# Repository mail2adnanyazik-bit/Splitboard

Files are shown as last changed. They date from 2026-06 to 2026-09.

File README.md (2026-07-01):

# Splitboard - a custom, built from scratch wireless corne split keyboard. Built for Stardance, to qualify for Outpost.

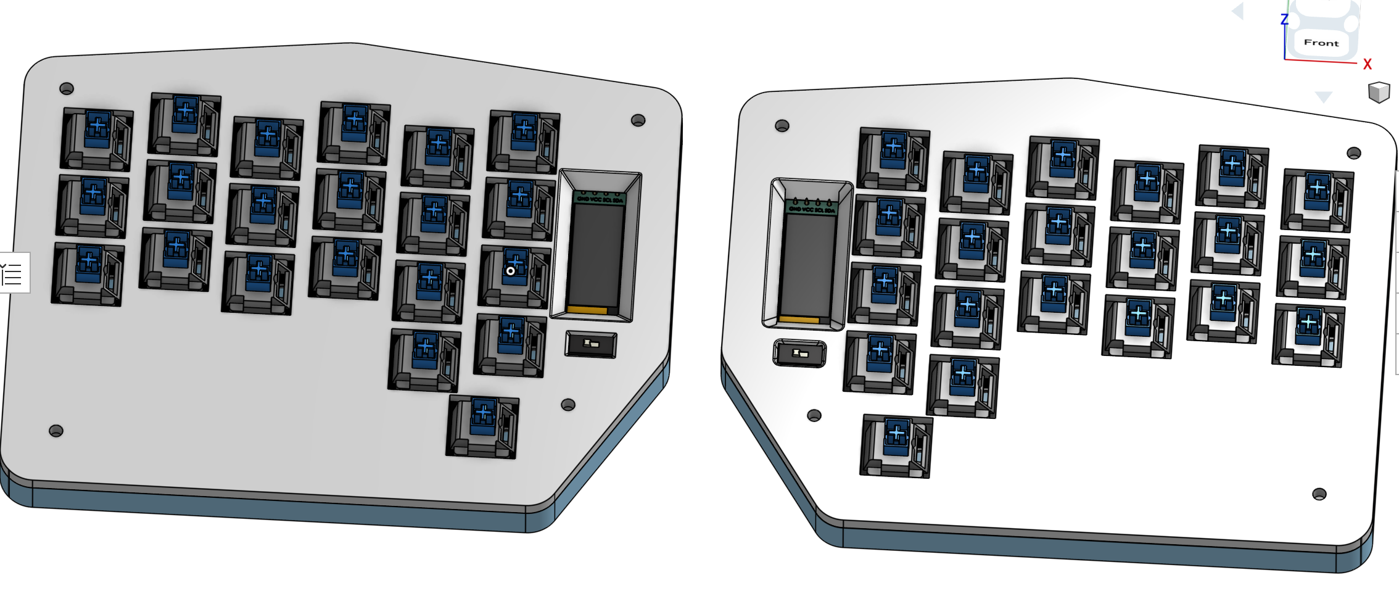
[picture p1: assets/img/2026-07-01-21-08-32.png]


Splitboard is a wireless split keyboard built by ME - Panda (also known as Adnan)

You see, my dad has had a dygma raise split keyboard since like 4 years, and i thought it looked REALLY cool, and wanted to get one -
till i saw the price - the thing was whopping **_200 DOLLARS_** ! So i thought to myself - why not build one myself ?

By the time this event rolled around, i was already getting tired of my very *anti-*ergonomic apple magic keyboard, and thought
that this project would be perfect, expecially cause of the experience with keyboards i got from the Hackpad mission.

That is how the **Splitboard** was born.

## Components :

Since this keyboard was made completely from scratch, i first will tell you whats its made of :

The Split Keyboard has 2 halves, with each having :

- 21 Keys (3x6 matrix with 3 thumb keys) - in the classic Corne layout
- One OLED (blue, since thats myt fav color)
- A supermini nrf52840 microcontroller - this is a cheap nice ! nano v2 clone, a wireless chip made excpecially with keyboards in mind
- A 110 mAh Battery (should last weeks with my setup)

So this is the Schematic with all mentioned components :

## Schematic :

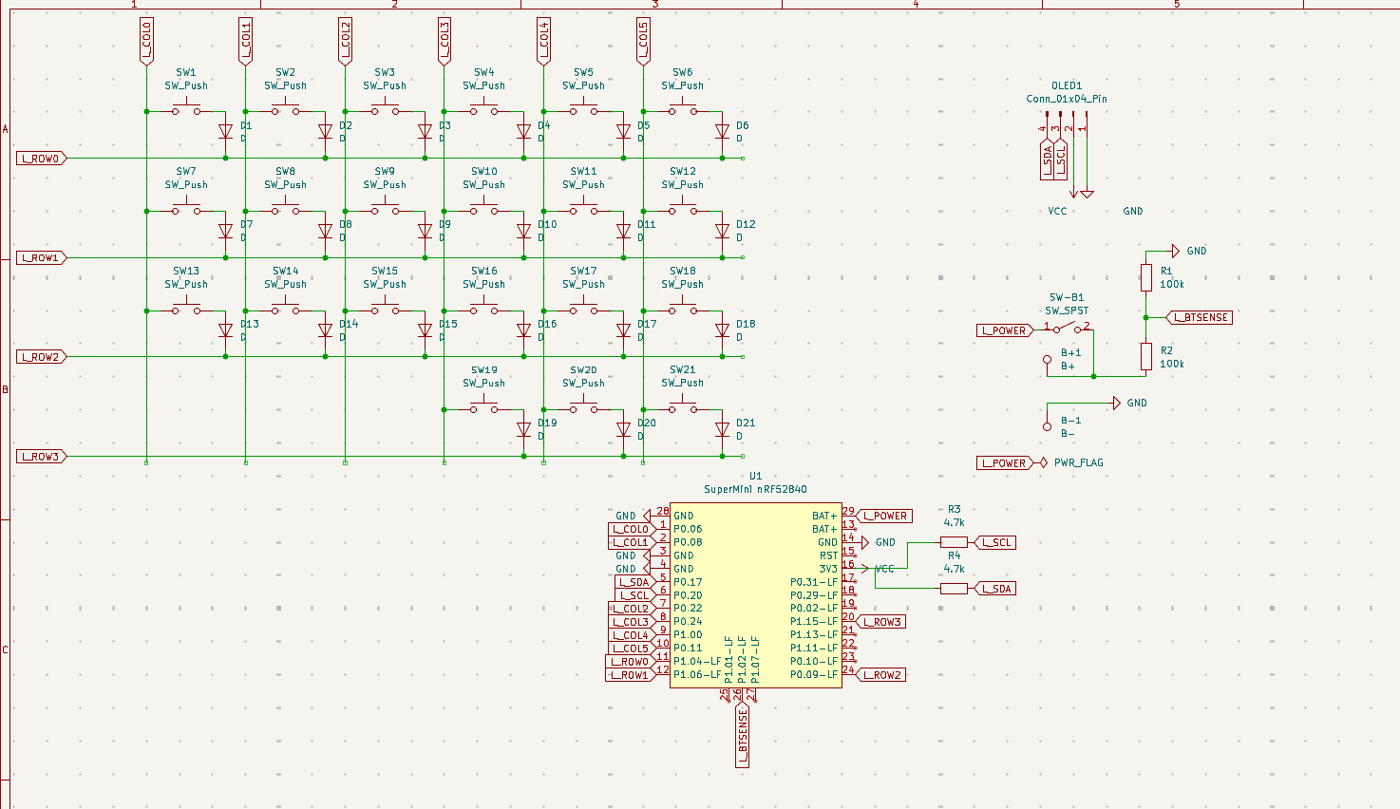
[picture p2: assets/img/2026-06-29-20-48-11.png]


As you can see, i dont like wires :D

## PCB :

left side :

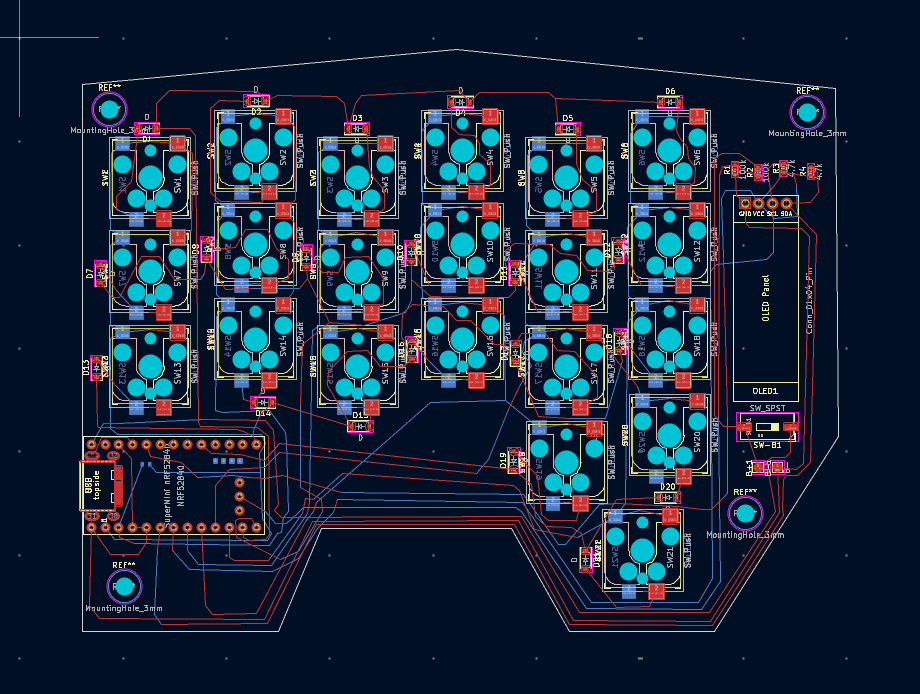
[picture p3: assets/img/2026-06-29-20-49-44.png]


right side :

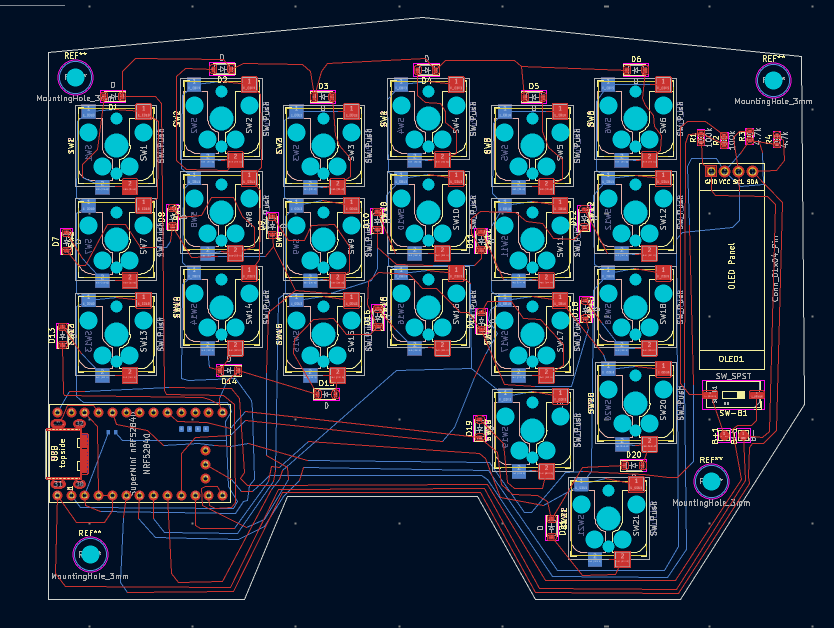
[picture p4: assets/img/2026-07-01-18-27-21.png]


Although the initial plan was to make a _reversible_ PCB that i would just turn 180 degrees, i decided to make my keyboard not symmetric - which means i cant just turn it around, instead i have to make two seperate PCB's

## Case :

You can view it interactively on OnShape in your Browser ! : https://cad.onshape.com/documents/4401902cdc607732e38adc1c/w/b44e538c7538a5811b6e646c/e/3efcd232ff04d945eef59e16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

For the case, i decided to use just two parts :

- ### A Case Bottom :

  This just holds the PCB and components for my keyboard

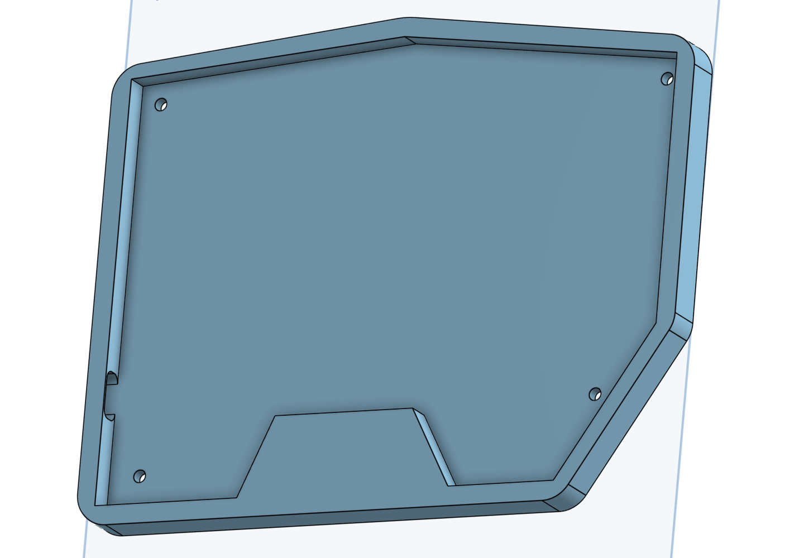
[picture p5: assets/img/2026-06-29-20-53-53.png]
  

- ### A Top Plate :
  This will be screwed on to the base, and has holes for the components that need to look out to poke out
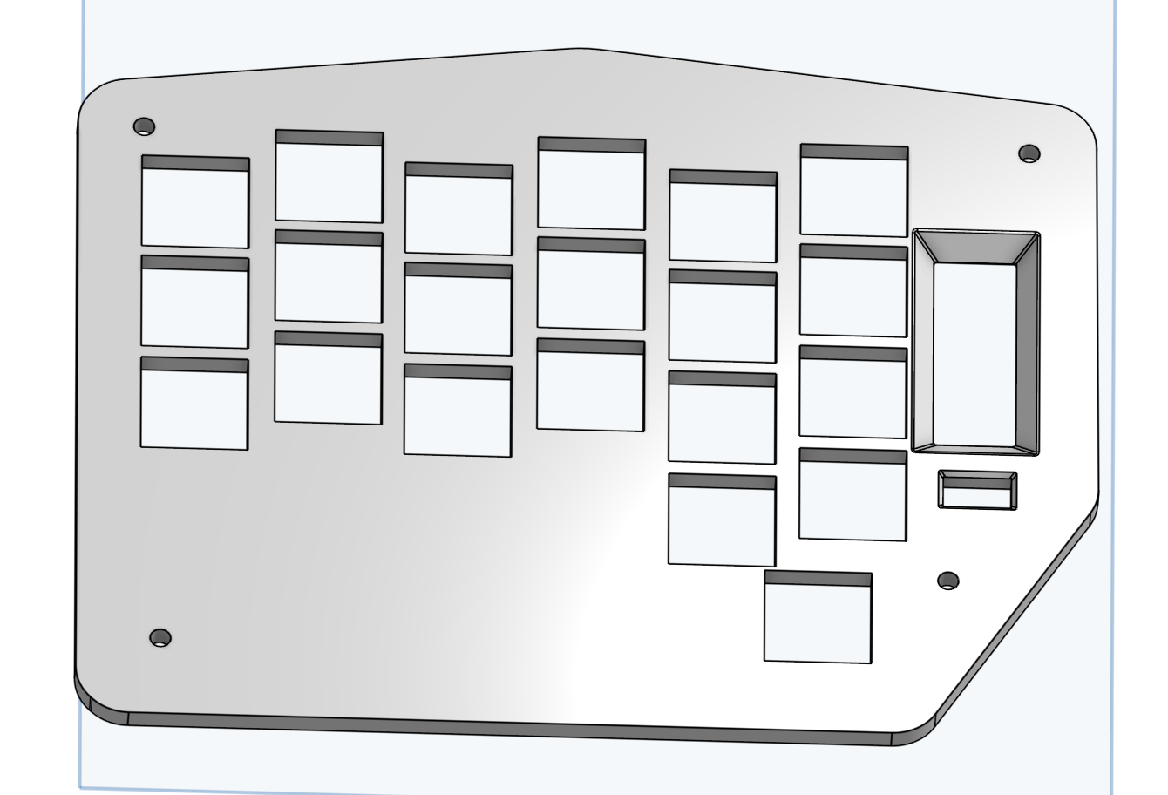
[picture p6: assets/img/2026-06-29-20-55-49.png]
  

## Assembly :

There will be a such Bottom and Top for both halves of the keyboard, and it will then be assembled like this :

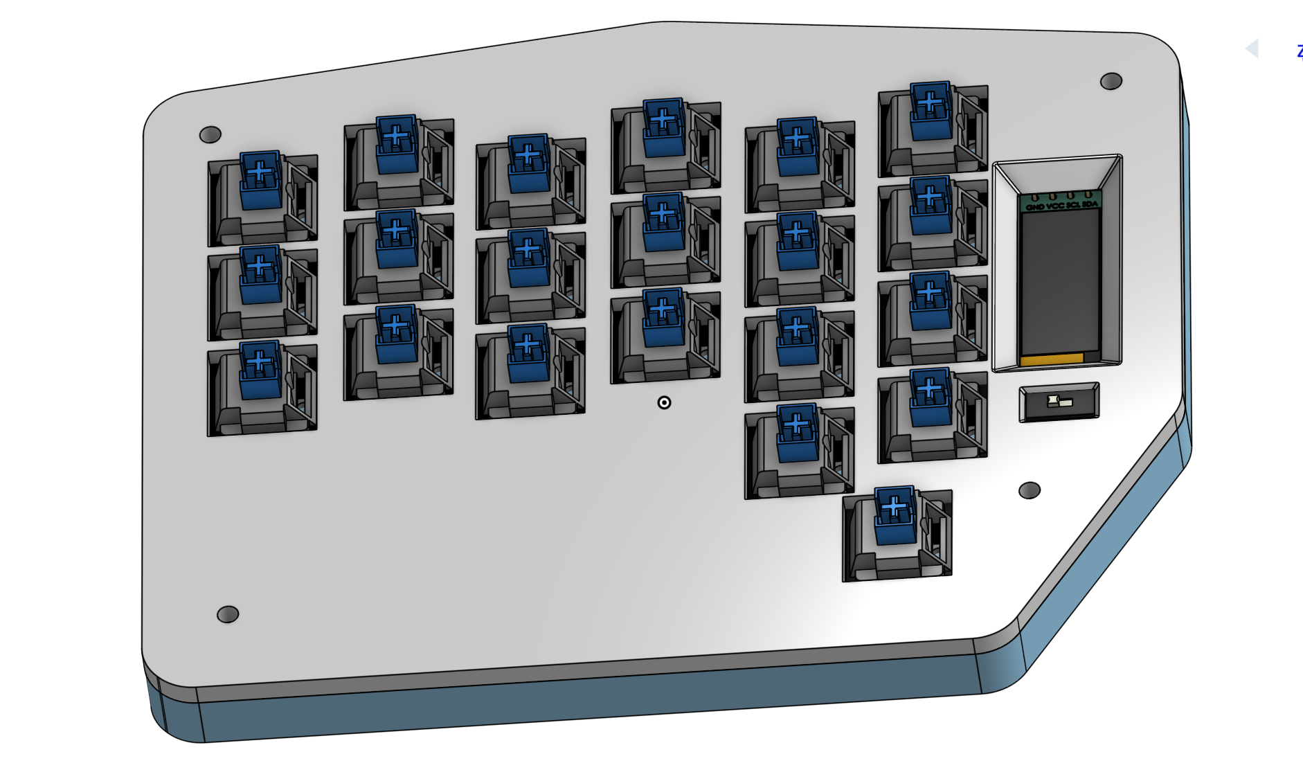
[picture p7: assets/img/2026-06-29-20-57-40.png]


Then Keycaps will be pressed on to the switches.

This will be done on both sides :

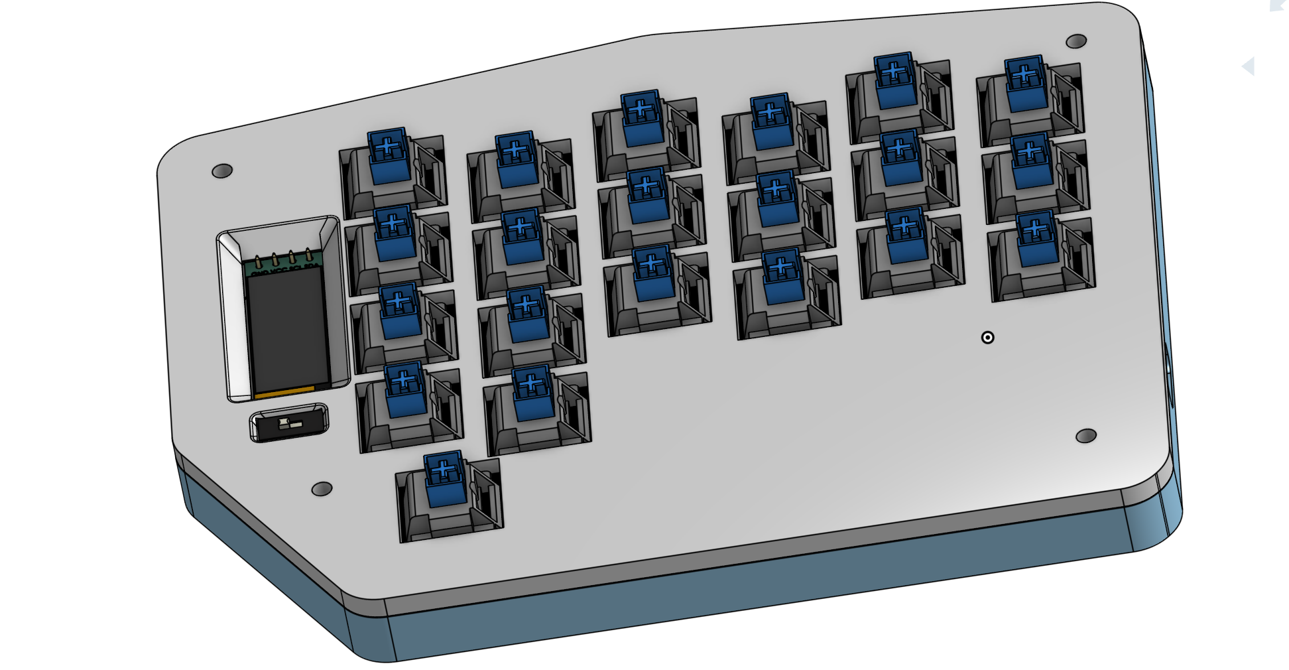
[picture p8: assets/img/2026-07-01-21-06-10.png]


In the end it will look like this :



## Firmware :

Because i had to make the firmware extremely fast for outpost, im just making a completely boring, standard corne keyboard firmware with ZMK

## Costs (BOM) :

I will buy everything except PCB from Aliexpress

2x supermini nrf52840 : 15 $
2x 110 mAh LiPo battery : 5 $
1N4148 SMD Diodes : 2 $
Kailh MX Hotswap sockets : ~ 7 $
42 x Cherry MX Switches : ~ 40 $
42 x Cherry MX Keycaps : 25 $
2 x 0.91" OLED Display : 6$
4.7kΩ SMD resistors : 1 $
100kΩ SMD resistors : 1$
SPST slide switches : 0.50 $
JST PH 2.0 2-pin connector (for battery) : 1 $
M2 standoffs + screws kit : 2 $
8mm self-adhesive bumpons (less glide) : 2 $
PCB from JLCPCB : 20 $
Shipping (Aliexpress and JLCPCB) : 15 $

**==IMPORTANT==** : This BOM is NOT accurate ! Check the actual BOM.csv file in the main branch

Total : ~ 115$

I would add another 15 - 20 dollar buffer since something is bound to go wrong, so in the end it would be around 160 dollars.

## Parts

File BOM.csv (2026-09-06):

Part Name | Type | Amount | Total price (cause most come in packs of 100 or more) | Reference for price
Corne PCB kit | PCB and components | 1.56$ | Aliexpress
115 in 1 screwdriver kit | Screwdriver and screws | 12.51$ | Aliexpress
Rubber bumpons | anti movement bumpons | 1 | 5.77$ | Aliexpress
Strong magnets (10 pcs) | magnets | 1 | 6.45$ | Aliexpress
Cherry MX blue switches | switches | 45 | 15.86$ | Aliexpress
Cherry MX Blue Keycaps | keycaps | 1 | 17$ | Aliexpress
Shipping | Shipping | 1 | 20$ | de.aliexpress.com and JLCPCB.com
Total (no shipping or buffer) : | 115$

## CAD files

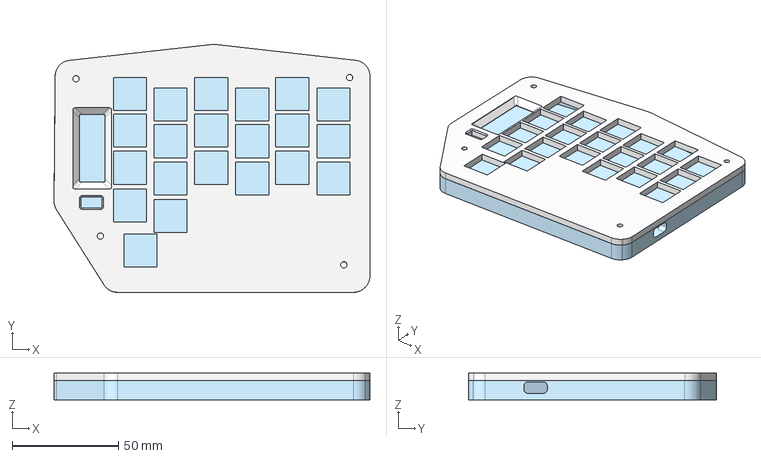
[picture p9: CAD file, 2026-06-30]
CAD/Assemblies/RightAssembly.step
148.6 x 116.6 x 12.5 mm

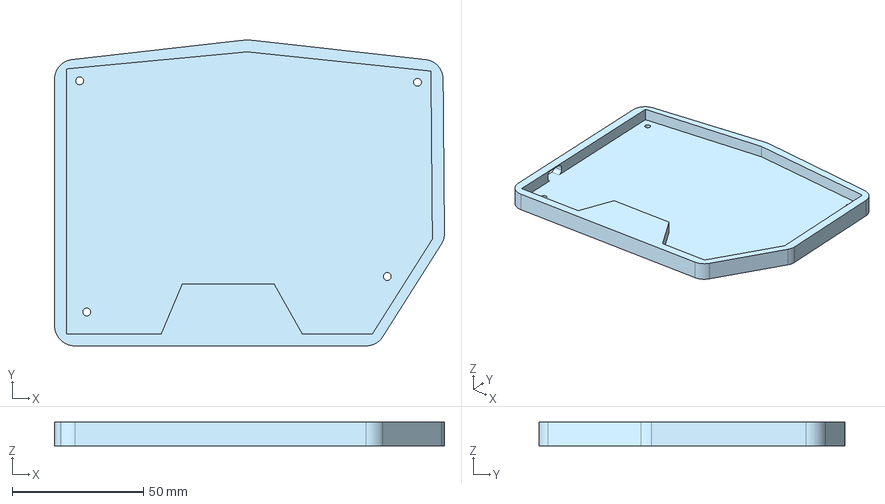
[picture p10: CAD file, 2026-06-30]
CAD/Case/Left/CaseBottomLeft.step
148.6 x 116.5 x 9.00 mm

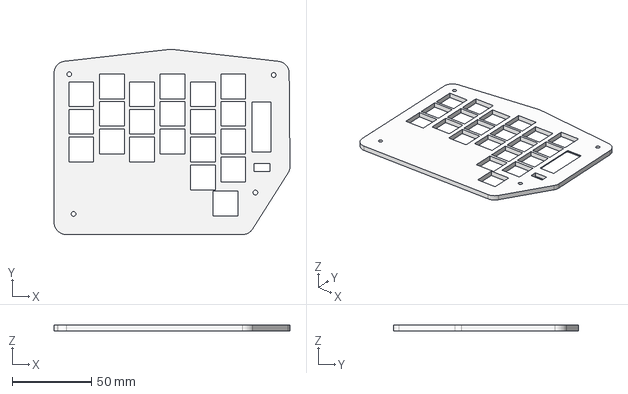
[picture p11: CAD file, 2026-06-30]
CAD/Case/Right/CaseTopRight.step
148.6 x 116.5 x 3.50 mm

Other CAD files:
CAD/Case/Left/CaseTopLeft.step
CAD/Case/Right/CaseBottomRight.step

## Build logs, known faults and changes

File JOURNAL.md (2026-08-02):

## June 15 : Research finished ! (~ 3h)

I am finally done with all my research, took major decisions for the final product and finished my components list with Deepseek's help !

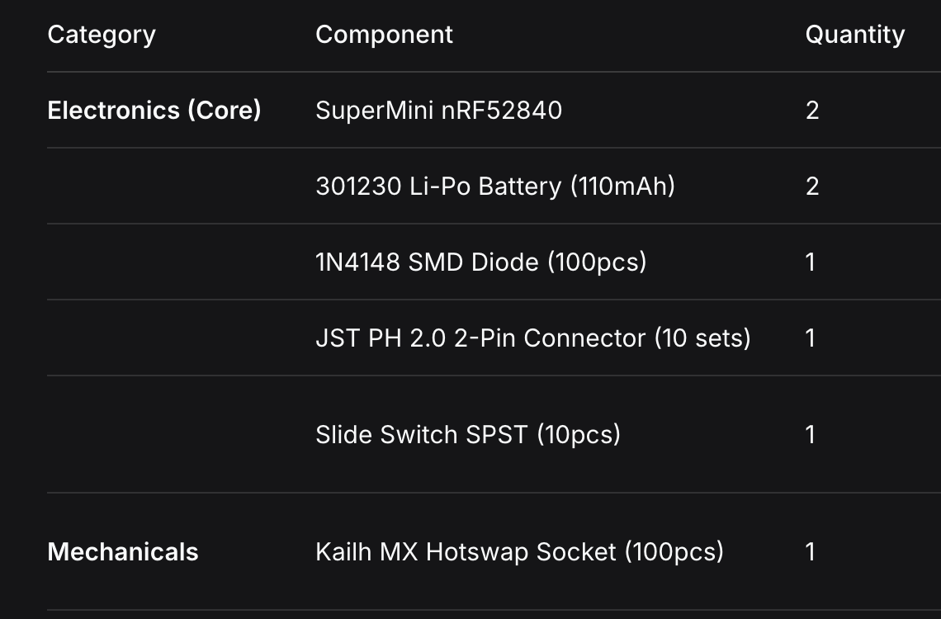
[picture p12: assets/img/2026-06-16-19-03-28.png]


### What I've decided on :

     - The keyboard will be a wireless split keyboard
     - It's layout will be a standard Corne : 42 total keys - 3x6 Switch matrix and 3 thumb keys per side
     - It will use a 110 mAh battery per side
     - The microcontroller will be a Supermini nrf52840 chip
     - It will additionally also have 2 OLED's : One to display the Layer (im a kb warrior lmao) and one for battery percentage and connectivity
     - It will of course have an off/on switch
     - I will be using cherry mx switches, WHICH ARE REALLY EXPENSIVE - i never would have thought that a cherry mx official switch cost almost 1$/switch
     - I will also use hotswapping adapters so I dont have to permanently stick with one type of switch
     - I will 3D print the case

## June 16 : Schematic done ! (~ 5h)

Done with Schematic ! It was a bit hard to figure out some things, find some footprints and symbols, and expecially with the wiring
and the wierd symbols for my microcontroller - also some of the components did'nt have symbols so i had to improvise.
It was hard to find out which symbols and footprints to use, but it was fun to see concepts i learned in physics class like voltage dividers with resistors being used !

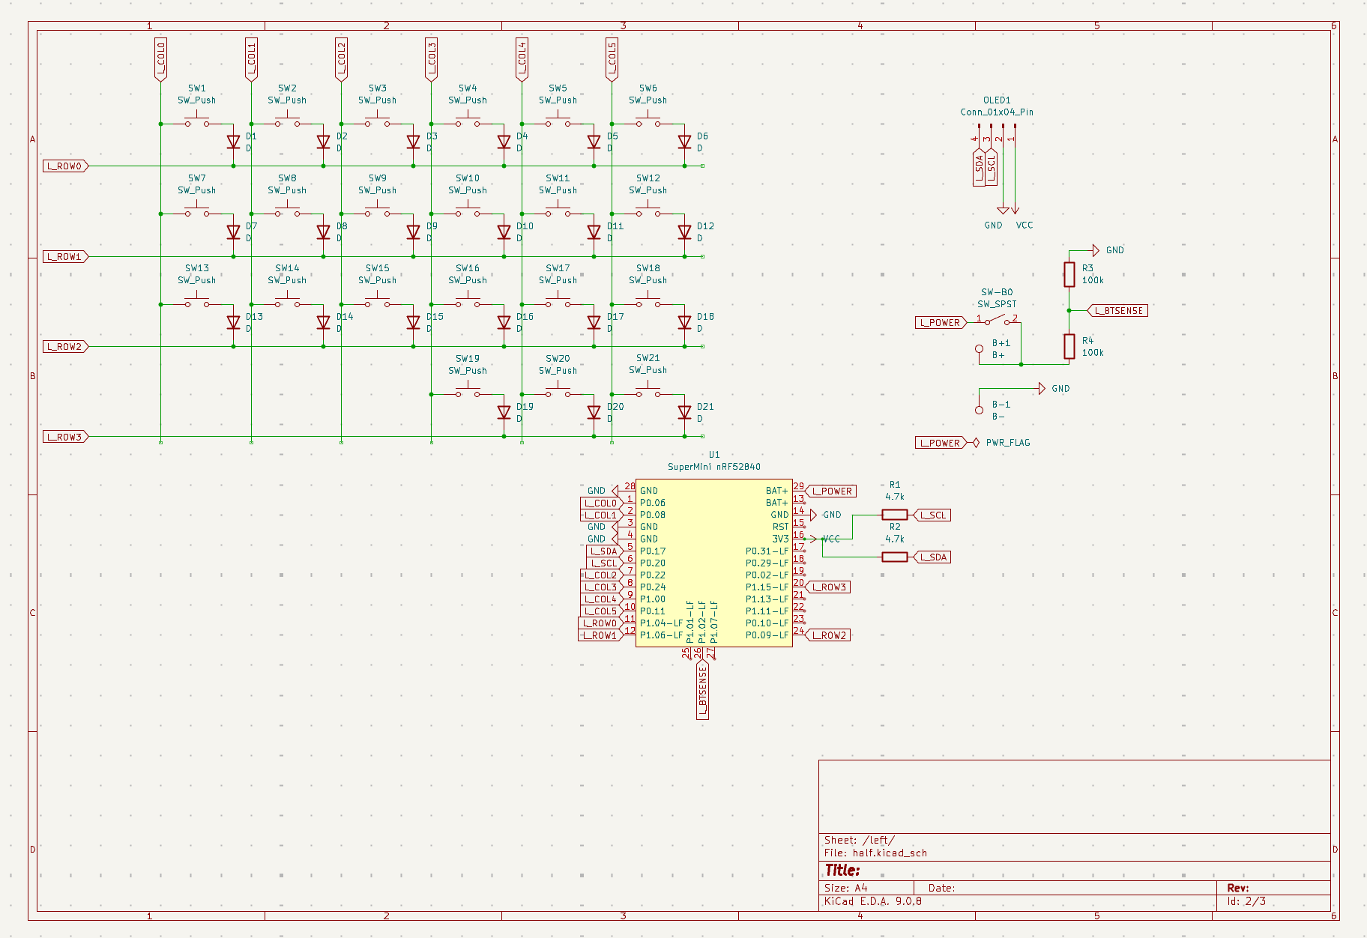
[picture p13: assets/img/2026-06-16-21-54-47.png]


## June 17 : PCB start ! (~ 2h)

I was finished arranging and wiring my PCB, and ran DRC, when Disaster struck - my footprint for the microcontroller was wrong !
I had to start again with a new footprint, and delete all the wires going there. And to add to my misery, I had forgotten to click unpause on my Recording, and lost next to 2 HOURS of work.
Here is the current state of my PCB :

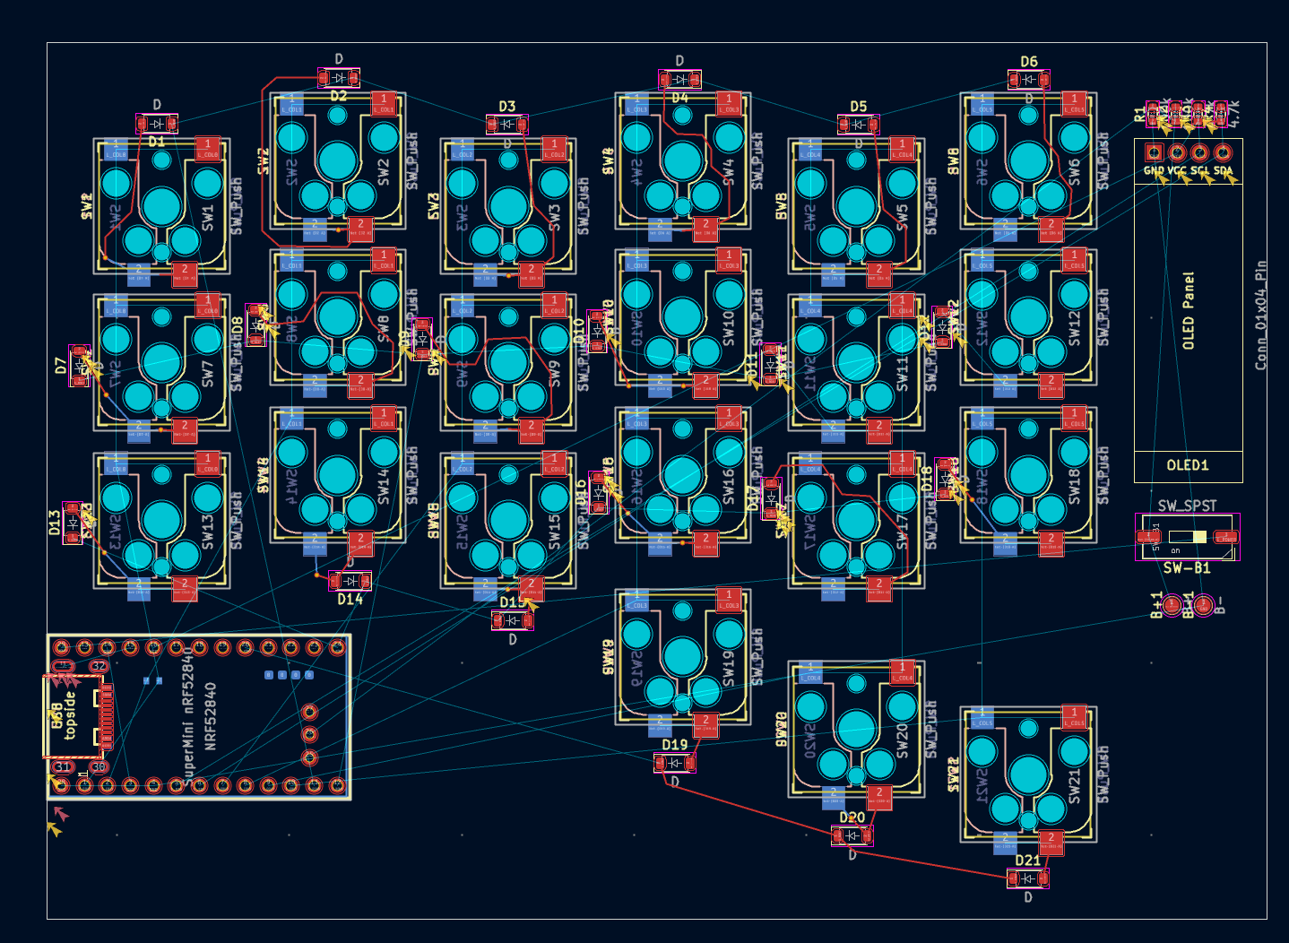
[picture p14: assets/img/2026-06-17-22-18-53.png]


## June 18 : PCB finished ! (~ 1h 30 min)

I had forgot to mention yesterday : I had made a revision to my PCB and Schematic!

I was before using one Schematic with two hierarchy sheets like the blueprint tutorial said, but that was growing troublesome with the Global labels,
and i would have had to wire the PCB twice, or take some long bypass that might not work in the end. Instead, i made a major decision for the final project :
I instead of putting both Sides in one project realized that I could just make the PCB for one half, then FLIP it over ! this was a major revelation, as this meant I only needed to design the schematic
and the PCB ONCE instead of twice, sparing me effort.

After realizing this, i started with the PCB :

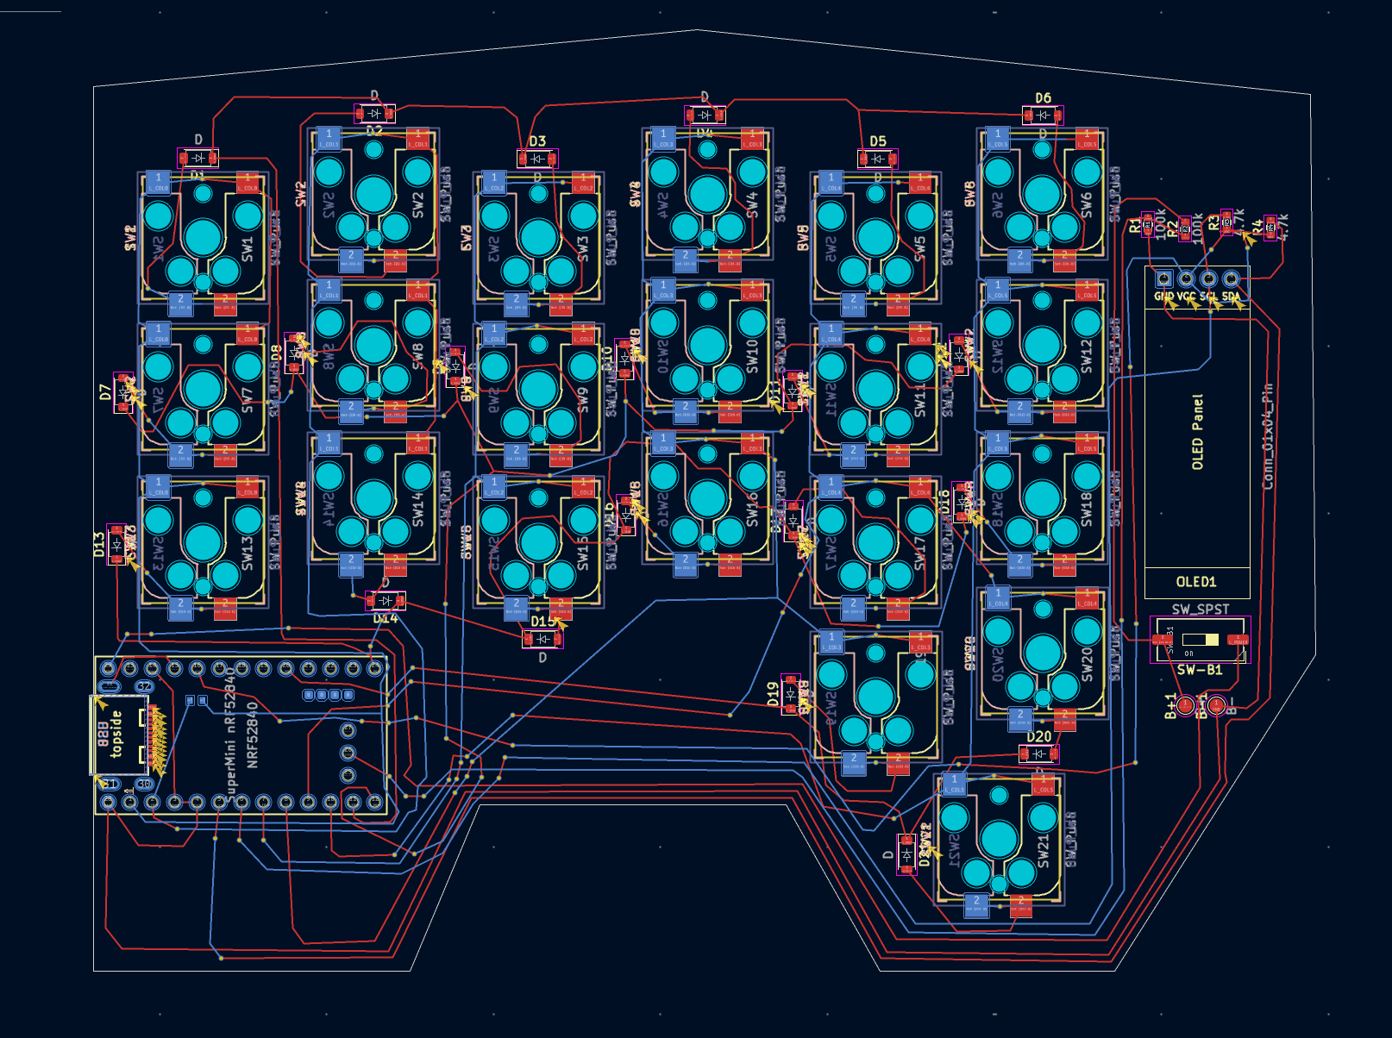
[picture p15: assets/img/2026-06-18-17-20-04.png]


I had really not wanted to use via's, but with the amount of components and wires on the PCB, it was impossible not to,
expecially cause i am still an amateur - this is only my second PCB ! It was also because of the design of the diode's and the hotswap sockets,
so it was rather unavoidable. I finished wiring though, and also made the Outline fo the board fit the board a bit better - im proud that im done now though !
Next time i hope i can do it better with the experience from this, and im a bit sad at the amount of vias used.

## Still June 18 :D : PCB Adjustment & 3D Models (~ 2h)

I added mounting holes to my PCB cause i realized that trying to make a case that snaps or slides shut with some mechanism that still holds the PCB
safe would be rather troublesome, and decided to cut my losses and add 4, at the approximated corners of my PCB

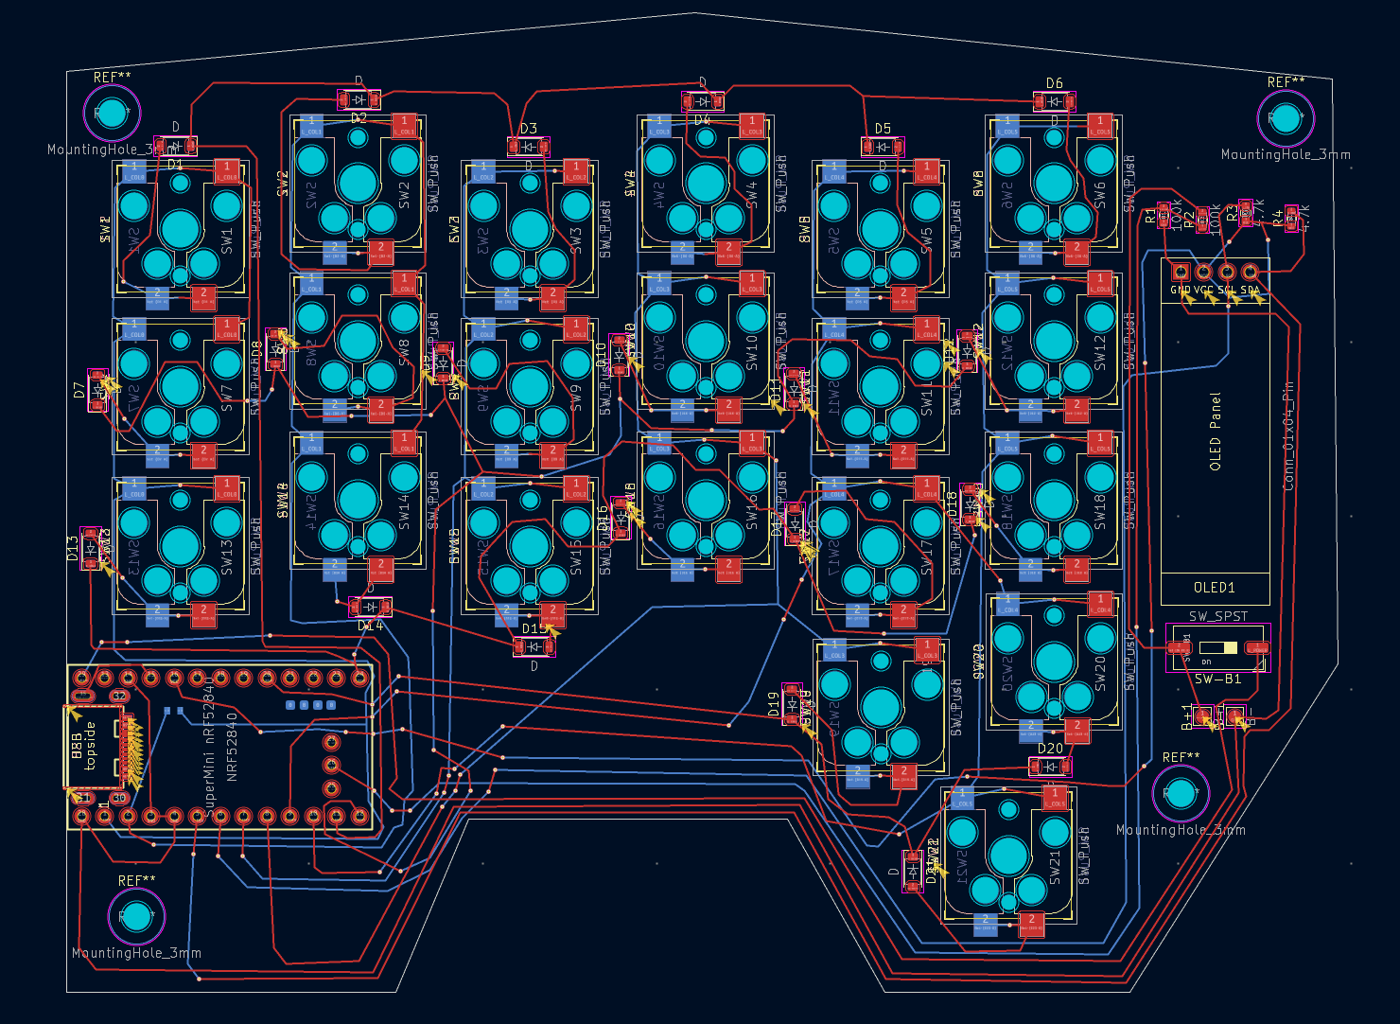
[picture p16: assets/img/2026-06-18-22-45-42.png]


I also started finding the CAD 3D models for my components and adding the 3D Models to their corresponding footprints
in KiCad itself, which will make is much easier than painstakingly hand-positioning them in a 3D modeling tool like OneShape one by one.
I think I have all the Footprints :

The 3D models for the battery test points, diodes, and resistors were already built in to KiCad, so i didnt have to do those,
but for the following :

    - Supermini nrf52840 (this took so long to find, as all of the one that were popping up first either were very vague approximations or were missing pin holes or other things)
    - Cherry MX Switches (There was a bit of trouble with this as well, as i got confused by two pins that are apparently only for support and can be snipped off - that was *wierd*)
    - Kailh MX Hotswap Sockets (these were easy to find, but it was a bit annoying to try and figure out on which side and how these are to be positioned on the PCB)
    - the OLED (i had this from the Hackpad already, so this was easy :D)

For each of these, i had to import the 3D model into KiCad and then position them so that the pins or protrusions go into the holes of the PCB, which was annoying, but better than doing that for EVERY component.

Here is a pic of the final PCB from the built in 3D viewer in KiCad:

#### Top

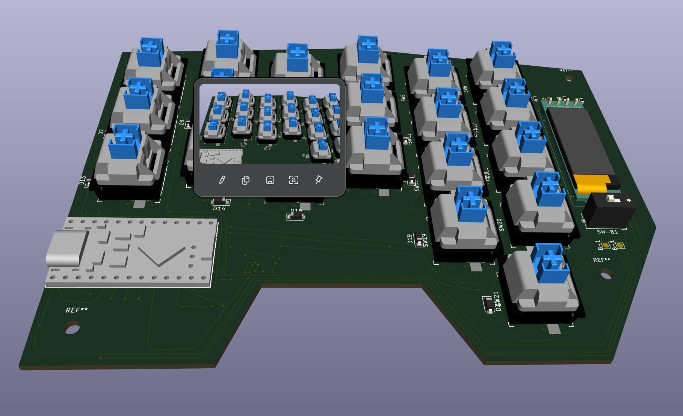
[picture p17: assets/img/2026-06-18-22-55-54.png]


#### Bottom

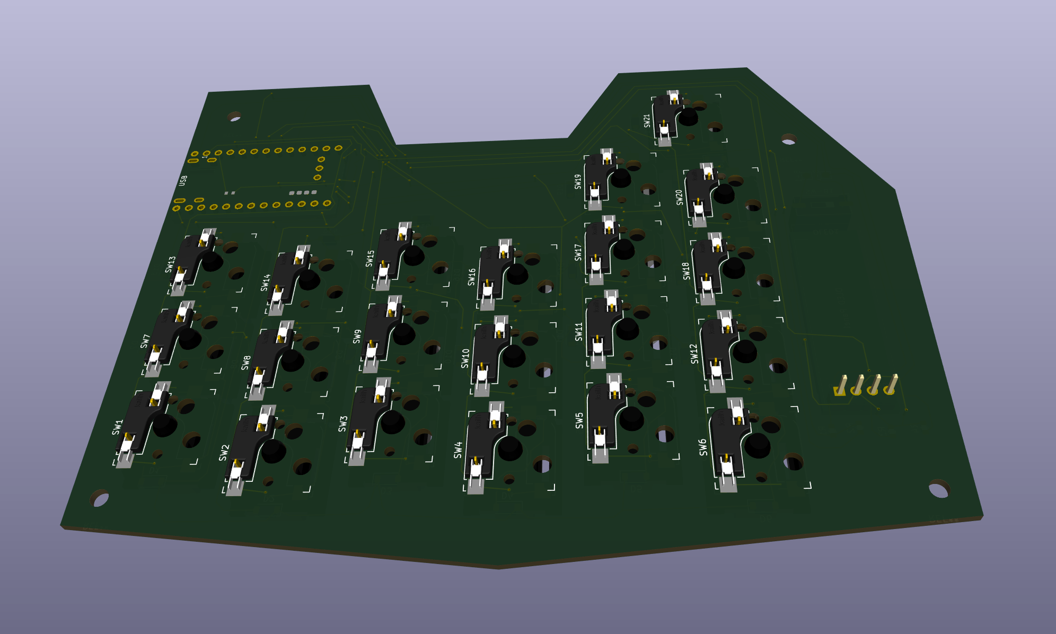
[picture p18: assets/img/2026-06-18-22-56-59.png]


## June 27 : 3D Modeling - Case Top (~ 4h)

After a long time of being lazy and working on the schematic for my other current project **_AquaPuck_** (_Psstt ... U should check it out ! Its also on Stardance ..._)
im back !

I started working on the 3D modeled Case for my SplitBoard ! I had a bit of experience from the **_PandaPad_** (My hackpad stardance project) for this part, only difference is, the Hackpad was 6 keys and 2 other Parts -
compared to that this thing is **MIND BLOWING** !

So what i did today was first plan - Just like for the PandaPad, i decided to use just 2 parts :

- The Case Bottom (A kind of hollow shell with space for the PCB)
- The Case Top (Basically a flat top for the Case Bottom with holes where the switches and screen or other components can poke through)

For now i decided to start with the Case Top, as the Bottom would be a lot complexer than the Top. Im realzing now that could be a mistake.

Anyway, to make the Top, this is what i started with - the 3D model for my PCB :

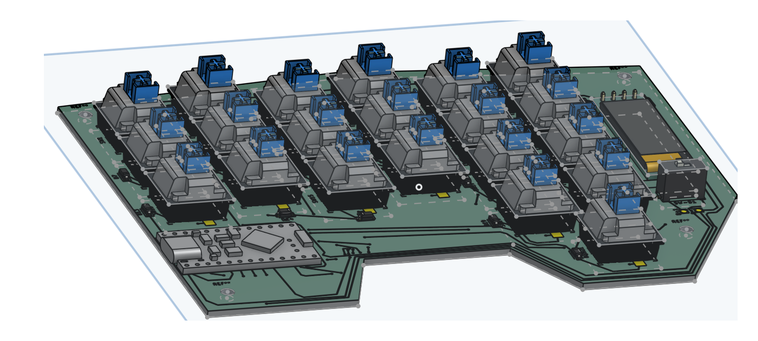
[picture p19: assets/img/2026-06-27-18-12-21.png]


I started counting the components that would poke through - these were :

- The Keyswitches
- The Power Switch
- The OLED Screen
- The screws

So i started drawing cutouts for all of them :

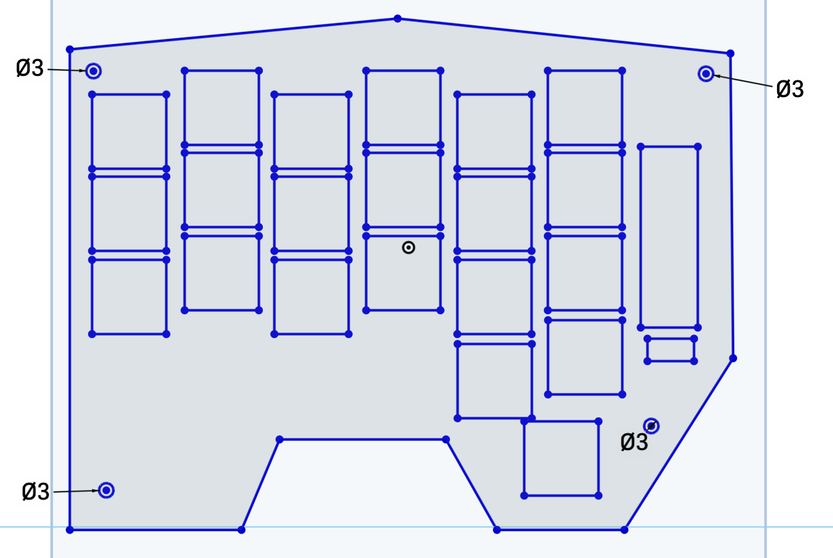
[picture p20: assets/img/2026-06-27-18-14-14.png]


This is just the first sketch with cutouts, as i will have to make the entire thing bigger later (this is currently only as big as the PCB - Since this attaches to the Case itself it will need to be as big as the case - and the case walls will also have thickness, get it ?)

After extruding (just for show !) :

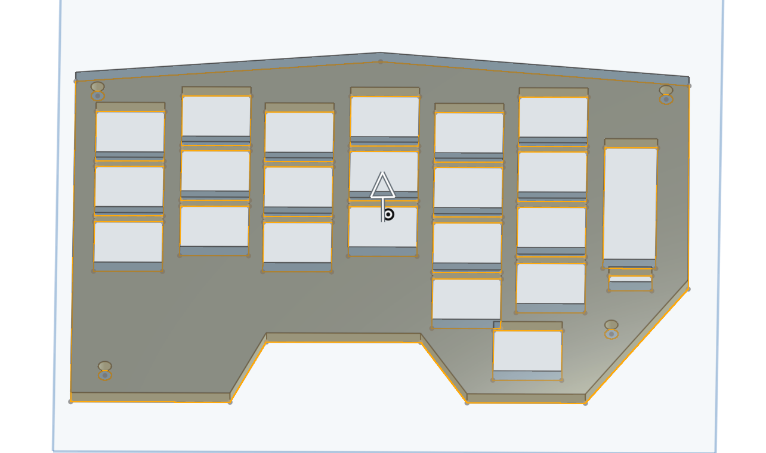
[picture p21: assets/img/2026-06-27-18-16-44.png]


## June 29 : 3D Modeling done ! (~ 4h)

So, after a whopping 4 HOURS of work, i have the 3D Models for both sides of the Case done :

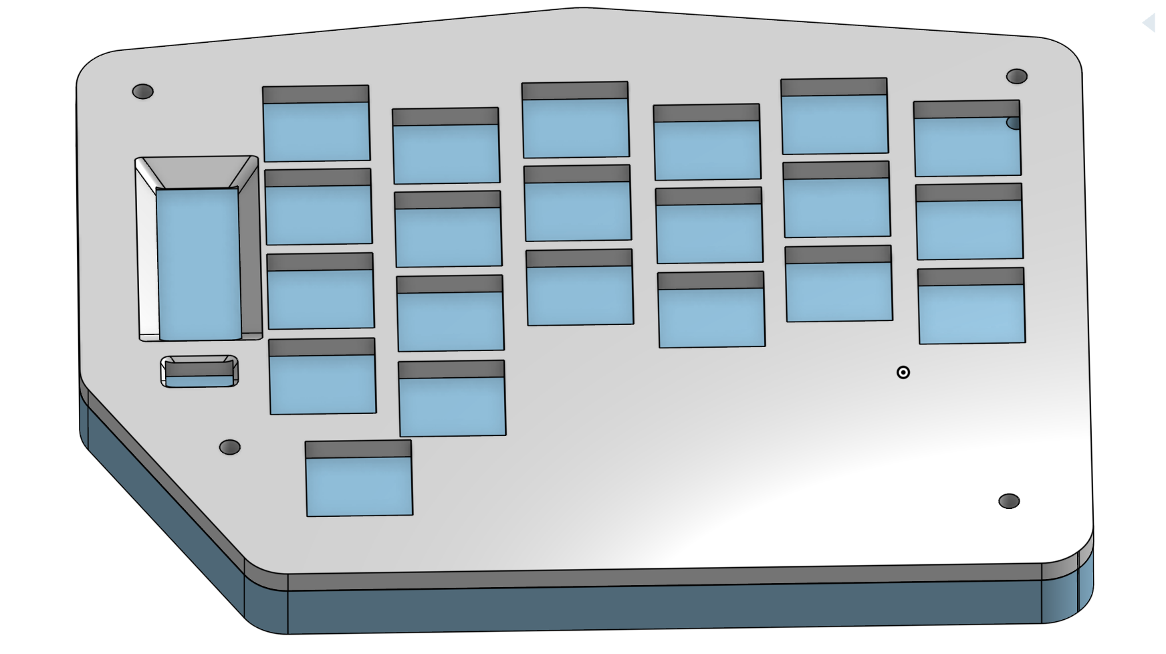
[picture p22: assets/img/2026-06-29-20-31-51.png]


Basically i took the outline of the PCB as a reference, made a second outline that was bigger, less exact, etc. and then added mounting holes and a cutout for the USB-C port
of my microcontroller

I also made it look good by rounding off corners, making the final outline a bit more bigger and less hugging the shape of the PCB.

I also polished the Case top in the same way.

Anyway, all i have left to do is set up the GitHub Repo and README

## July 11 : Grant got approved, code writing and waiting on parts ! (~ 16 hours)

So yeah, i got me grant ! \*toot **toot\*** !
Also i worked a lot on the code for it, and im proud of myself - and then my power went off cause i forgot to charge my laptop, and since
i recently switched to neovim, i dont have autosaving and instead accidentally deleted all my work cause i only save at the end. **UGHHHHH**
fortunately i have hackatime and the time is saved in there, so i can still get stardust for it and can prove i worked 18 hours on the project software :D

I also think i found a cheaper local german alternative to aliExpress and its crazy ass shipping - but now i might have to change my PCB cause it has too many vias cause im an idiot who does not know how to wire T-T.
i knew this would come back to haunt me dude.

Anyway im gonna wait for my dad to get back from his 1 month long trip before i order the parts cause he can definetely help me with that, so
im not gonna be working on the project for a while :/ .

I have decided its probably better to FIRST do hardware THEN do software (cause its useless if it doesnt work or i change the PCB)

### UPDATE

ok i just checked JLCPCB and i _thiiink_ my PCB is fine ? im not exactly sure but i think so - it could be anywhere between 10 and 80 $ T-T

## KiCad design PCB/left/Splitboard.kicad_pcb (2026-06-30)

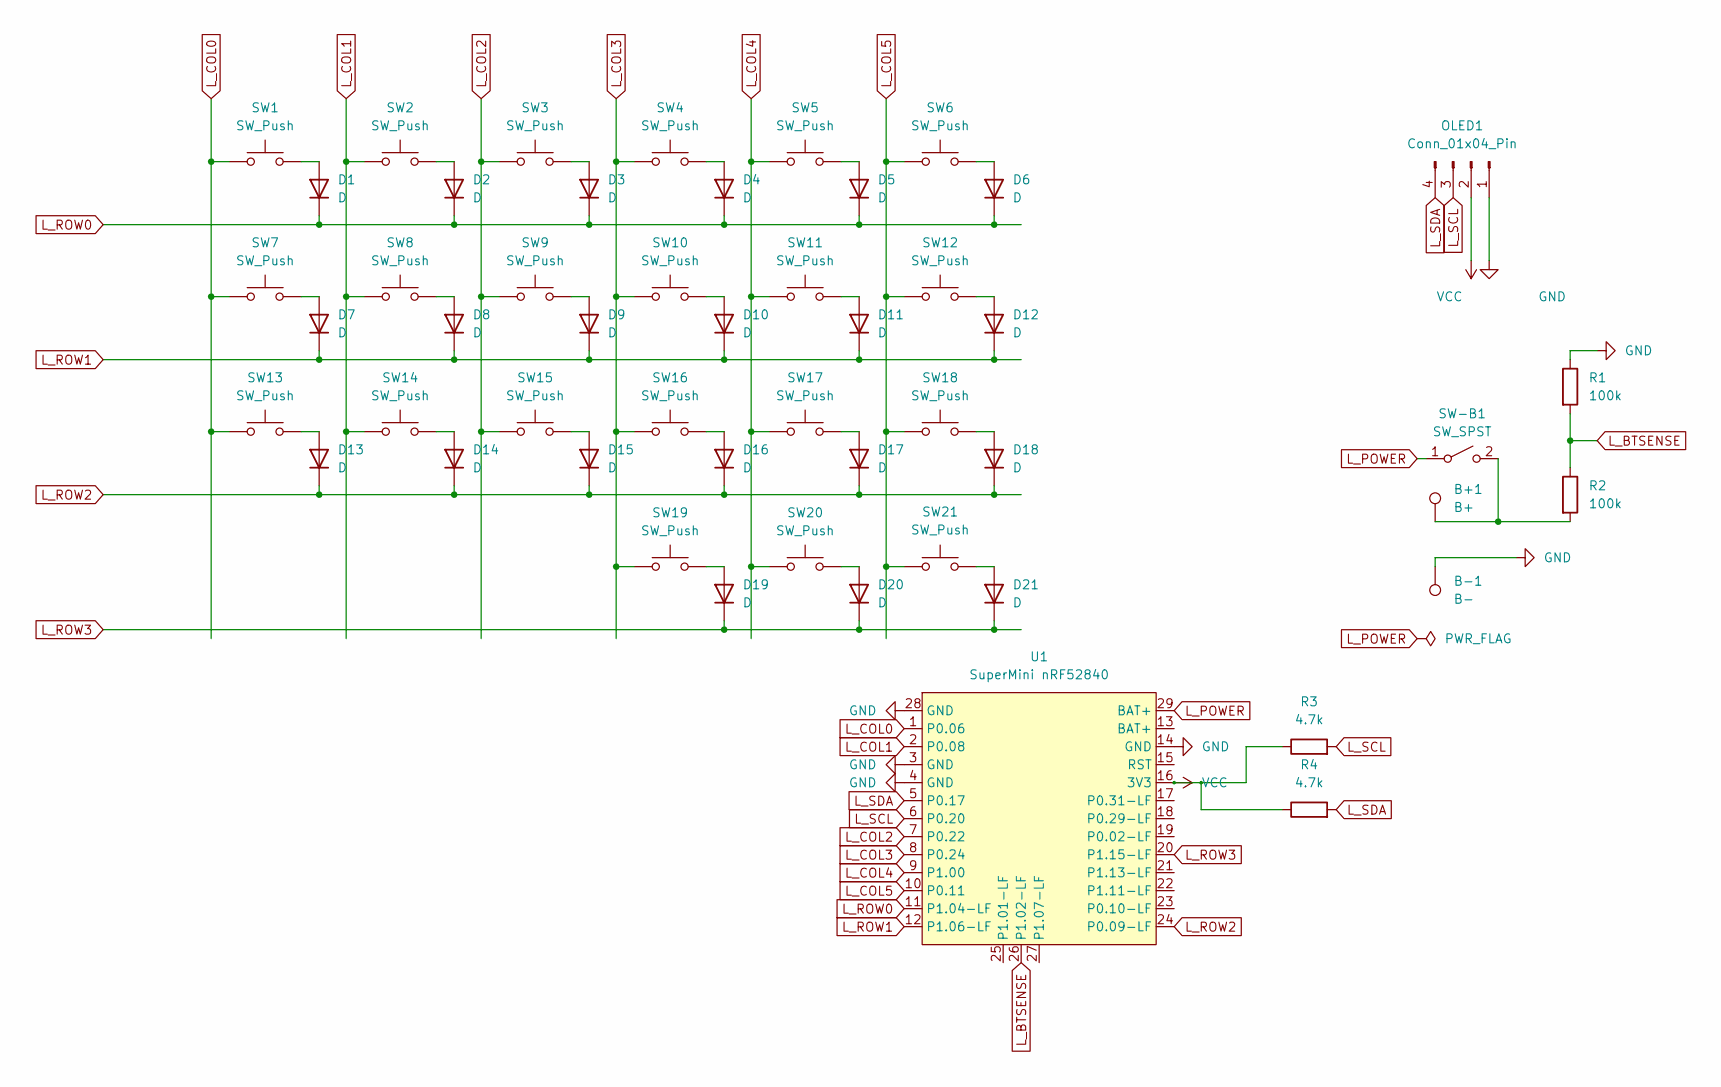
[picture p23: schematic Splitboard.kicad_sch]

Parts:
B+1: B+; TestPoint_Pad_1.5x1.5mm
B-1: B-; TestPoint_Pad_1.5x1.5mm
D1, D2, D3, D4, D5, D6, D7, D8, D9, D10, D11, D12, D13, D14, D15, D16, D17, D18, D19, D20, D21: D; D_SOD-123
OLED1: Conn_01x04_Pin; SSD1306-0.91-OLED-4pin-128x32
R1, R2: 100k; R_0603_1608Metric
R3, R4: 4.7k; R_0603_1608Metric
SW1, SW2, SW3, SW4, SW5, SW6, SW7, SW8, SW9, SW10, SW11, SW12, SW13, SW14, SW15, SW16, SW17, SW18, SW19, SW20, SW21: SW_Push; Kailh_socket_MX_reversible
SW-B1: SW_SPST; SW_DIP_SPSTx01_Slide_9.78x4.72mm_W8.61mm_P2.54mm
U1: SuperMini nRF52840; supermini

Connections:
GND: B-1.1, OLED1.1, R1.1, U1.3 (GND), U1.4 (GND), U1.14 (GND), U1.28 (GND)
L_BTSENSE: R1.2, R2.1, U1.26 (P1.02-LF)
L_COL0: SW1.1, SW7.1, SW13.1, U1.1 (P0.06)
L_COL1: SW2.1, SW8.1, SW14.1, U1.2 (P0.08)
L_COL2: SW3.1, SW9.1, SW15.1, U1.7 (P0.22)
L_COL3: SW4.1, SW10.1, SW16.1, SW19.1, U1.8 (P0.24)
L_COL4: SW5.1, SW11.1, SW17.1, SW20.1, U1.9 (P1.00)
L_COL5: SW6.1, SW12.1, SW18.1, SW21.1, U1.10 (P0.11)
L_POWER: SW-B1.1 (A), U1.29 (BAT+)
L_ROW0: D1.1 (K), D2.1 (K), D3.1 (K), D4.1 (K), D5.1 (K), D6.1 (K), U1.11 (P1.04-LF)
L_ROW1: D7.1 (K), D8.1 (K), D9.1 (K), D10.1 (K), D11.1 (K), D12.1 (K), U1.12 (P1.06-LF)
L_ROW2: D13.1 (K), D14.1 (K), D15.1 (K), D16.1 (K), D17.1 (K), D18.1 (K), U1.24 (P0.09-LF)
L_ROW3: D19.1 (K), D20.1 (K), D21.1 (K), U1.20 (P1.15-LF)
L_SCL: OLED1.3, R3.2, U1.6 (P0.20)
L_SDA: OLED1.4, R4.2, U1.5 (P0.17)
unnamed: D1.2 (A), SW1.2
unnamed: D2.2 (A), SW2.2
unnamed: D3.2 (A), SW3.2
unnamed: D4.2 (A), SW4.2
unnamed: D5.2 (A), SW5.2
unnamed: D6.2 (A), SW6.2
unnamed: D7.2 (A), SW7.2
unnamed: D8.2 (A), SW8.2
unnamed: D9.2 (A), SW9.2
unnamed: D10.2 (A), SW10.2
unnamed: D11.2 (A), SW11.2
unnamed: D12.2 (A), SW12.2
unnamed: D13.2 (A), SW13.2
unnamed: D14.2 (A), SW14.2
unnamed: D15.2 (A), SW15.2
unnamed: D16.2 (A), SW16.2
unnamed: D17.2 (A), SW17.2
unnamed: D18.2 (A), SW18.2
unnamed: D19.2 (A), SW19.2
unnamed: D20.2 (A), SW20.2
unnamed: D21.2 (A), SW21.2
unnamed: B+1.1, R2.2, SW-B1.2 (B)
VCC: OLED1.2, R3.1, R4.1, U1.16 (3V3)

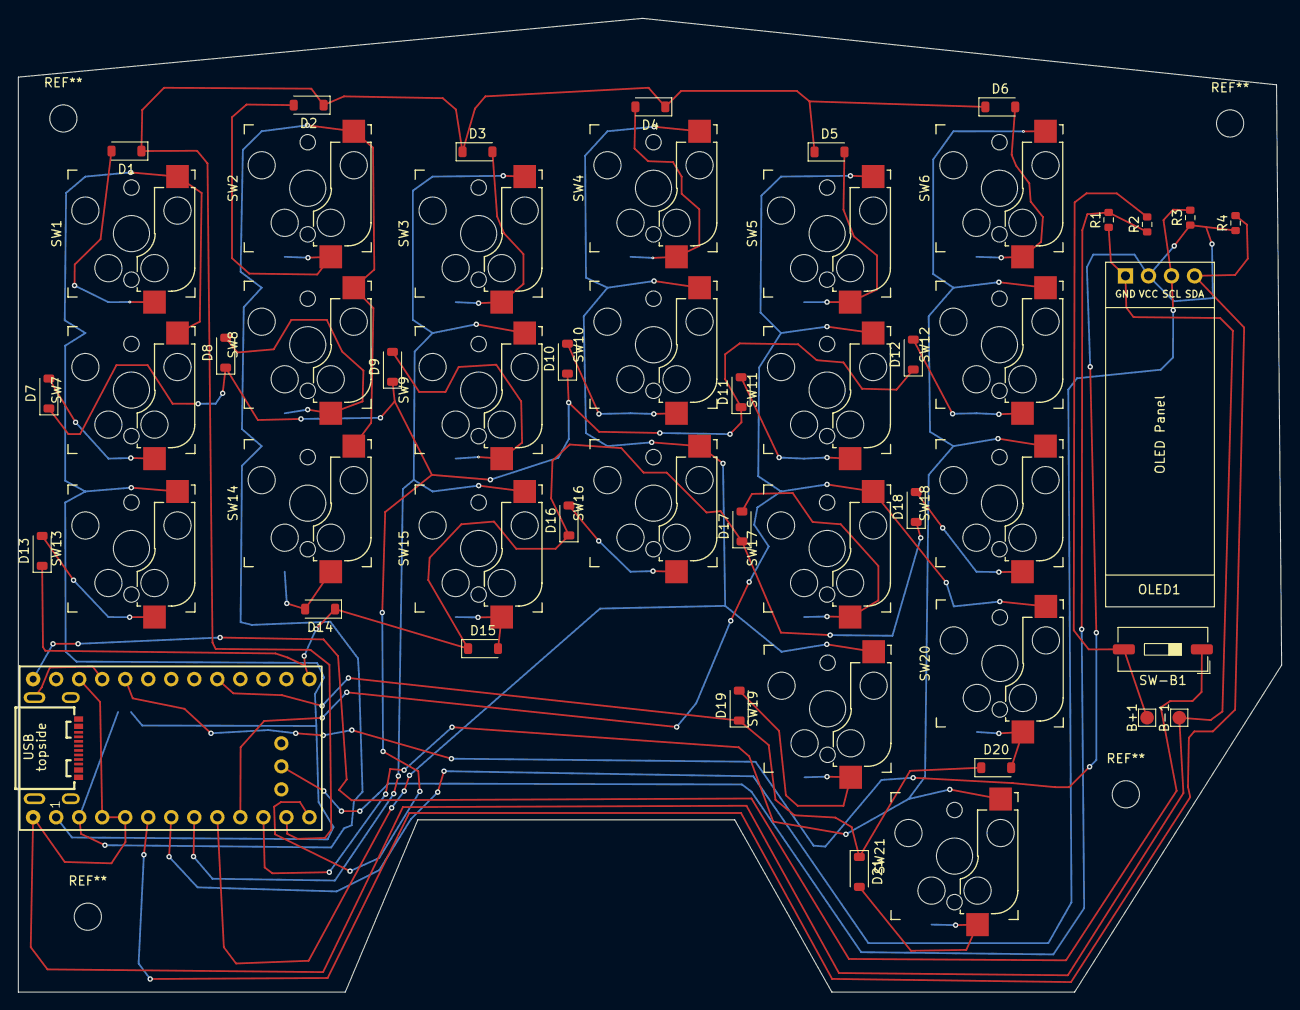
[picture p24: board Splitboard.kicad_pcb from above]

Board: 2 copper layers, 139.3 x 107.4 mm, 51 parts (0 on the bottom side), 38 nets.

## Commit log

2026-06-30 adjust according to feedback
    [BOM.csv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]
2026-06-30 adjust BOM to use cheaper components
    [BOM.csv]
2026-06-30 add shipping, fix price mismatch
    [BOM.csv]
2026-07-01 fixed PCB to be non-reversible as reversible wouldnt work
    [Splitboard-B_Cu.gbr, Splitboard-B_Mask.gbr, Splitboard-B_Paste.gbr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]
2026-07-01 README BOM clarification
2026-09-06 Clear up BOM
    [BOM.csv]
